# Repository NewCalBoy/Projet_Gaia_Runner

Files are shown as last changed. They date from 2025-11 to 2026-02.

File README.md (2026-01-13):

# Projet Gaïa Runner
Projet de 2ème année 2025 by SERAPHIN Bradley et DAVERAT Arthur

## Description du projet
Le projet consiste a créer un petit robot de type rover avec un bras articulé. La particularité du projet est qu'il est à architecture déporté, c'est-à-dire que le contrôle des roues est gérée par un microcontrôleur, autre que le microcontrôleur principal.

Voici ci-joint un exemple de rover avec un bras articulé.
ExempleGR

Dans un premier temps nous réaliserons d'abord le châssis, puis nous réaliserons dans un second temps la pince.

## Différentes parties
### Partie 1 : Rover
### Partie 2 : Bras robotisé
### Partie 3 : Pilotage
## Présentation
Lien de la présentation : https://www.canva.com/design/DAG3vKNjyPE/KJl2cilKYN6kFEWi7G_Mkw/edit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

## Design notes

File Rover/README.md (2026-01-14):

# Partie 1 : Rover
La partie mobile, dite le Rover, se décompose en 2 partie, les PCBs Esclave c'est-à-dire ceux des roues et le PCB Maître c'est à dire celui qui gère la partie Rover et le bras robotisé.

## Architecture déportée (Avantages et Inconvénients)
L'avantage d'une architecture déportée comme celle choisit pour le Rover est que c'est modulable. En effet chaque PCB Esclave contrôle un moteur et est en liasion I2C avec le PCB Maître, ce qui permet de __passer d'une structure à 4 roues motrices à 6 ou bien 2 roues motrices__.

L'incovénient est que plusieurs PCBs impliquent potentiellement __plus de PCB en panne__.

Voici ci-dessous un schéma du Rover



_Figure 1 : Schéma du Rover_

## Détaille du châssis
Les différentes solutions techniques retenues sont :

<details>
  <summary><strong>Les moteurs DC FIT0186 de chez DFROBOT (JGB37-3530B)</strong></summary>  

Comme le projet consiste à commander le robot le choix d'un moteur DC est pertinent, de plus le modèle choisit présente un encodeur ce qui permet un asservissement en vitesse si nécessaire. Plus de détail dans [Moteur DC](https://github.com/FumesecALPHA/Projet_Gaia_Runner/blob/main/Rover/Moteur_DC).
  
</details>
<details>
  <summary><strong>Les roues omnidirectionnelles</strong></summary>  

Le choix des roues omnidirectionnelles vient du faites qu'il s'agit du moyen le plus adapté pour déplacer notre robot avec une architecture à 4 roues motrices. Plus de détail dans [Roues omnidirectionnelles](https://github.com/FumesecALPHA/Projet_Gaia_Runner/blob/main/Rover/Roues_omnidirectionnelles).
  
</details>
<details>
  <summary><strong>Les PCBs Esclave</strong></summary>  

Le but de ces PCBs est de séparer le contrôle des moteurs DC du PCB Maître, cela permet de s'adapter à un châssis avec 4, 6 ou encore 2 roues motrices. Plus de détail dans [PCB Esclave](https://github.com/FumesecALPHA/Projet_Gaia_Runner/tree/blob/main/Rover/PCB_Slave).
  
</details>

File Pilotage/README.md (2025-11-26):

# Partie 3 : Pilotage
## Description
Cette sous partie concerne la commande du Gaïa Runner, c'est-à-dire l'usage du module Bluetooth pour controler le robot à distance.

## Solution technique
Pour le pilotage du robot, la solution choisit est d'utiliser un module Bluetooth HC05. Il sera connecté sur le PCB principal.

Module Bluetooth HC05

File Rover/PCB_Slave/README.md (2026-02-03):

# PCB Esclave

## Description
Voici le PCB Esclave qui a pour but de gérer la commande des moteurs DC.
<p align="center">
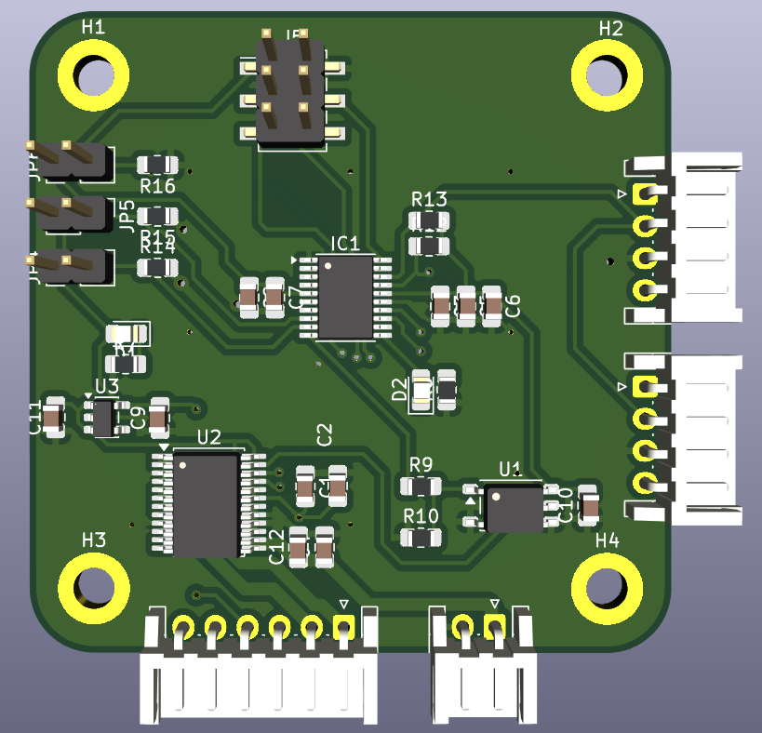
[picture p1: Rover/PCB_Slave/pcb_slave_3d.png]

</p>

Il y a 4 composants principaux : le microcontrolleur, le pont H, le LDO et l'optocoupleur.
Nous avons également 4 connecteurs JST : deux JST pour  l'I2C, un jst pour l'alimentation et un pour le moteur.

## Fonctionnement
### Etape 1
Le PCB Maître communique un octet avec le PCB Esclave via I2C. 
En fonction de la combinaisons des jumpers, l'adresse I2C du PCB Esclave est différente plus de détails dans la section [Adressage I2C]().
### Etape 2
En fonction de l'octet reçu, le PCB Esclave sait s'il doit avancer ou reculer et la vitesse attendue.

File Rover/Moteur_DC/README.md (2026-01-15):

# Moteur DC

Les moteurs choisient sont des moteurs 12V 251 tr/min 18 kg/cm de chez DFROBOT ([Roboshop](https://eu.robotshop.com/fr/products/moteur-dc-12v-251rpm-encodeur?qd=8a6a3a82e29a9eef824b3c39f723b023) ou [DFROBOT](https://www.dfrobot.com/product-634.html))  

## Pourquoi ce choix ?
<ins> __Modélisation :__ </ins>    
On modélise la situation de la façon suivante :  

<ins> __Bilan des forces :__ </ins>  
  
¤ $\overrightarrow{P}$ : le poids  
¤ $\overrightarrow{C_{m1}}$ : couple __d'un__ moteur
¤ $\overrightarrow{F}$ : force d'adhérence
¤ $\overrightarrow{F_r}$ : réaction du support

<ins> __Calcul :__ </ins>  
  
On sait que $\overrightarrow{C_{m1}}=\frac{\overrightarrow{F_{m1}}}{R}$, donc $\overrightarrow{F_{m1}}=\overrightarrow{C_{m1}}*R$  
  
D'après la 2nd loi de Newton :  
  
$\overrightarrow{F_{m1}}+\overrightarrow{F}+\overrightarrow{P}+\overrightarrow{F_r}=m\overrightarrow{a}$

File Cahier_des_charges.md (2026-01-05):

# Cahier des charges
## Partie 1 : Rover


## Partie 2 : Bras articulé


## Partie 3 : Pilotage


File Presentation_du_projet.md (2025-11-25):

# Projet_Gaia_Runner
Projet de 2ème année 2025 by SERAPHIN Bradley et DAVERAT Arthur

## Description du projet
Le projet consiste a créer un petit robot de type rover avec un bras articulé.

Voici ci-joint un exemple de rover avec un bras articulé.
Exemple de rover avec un bras articulé

Dans un premier temps nous réaliserons d'abord le châssis, puis nous réaliserons dans un second temps la pince.

## Présentation
Lien de la présentation : https://www.canva.com/design/DAG3vKNjyPE/KJl2cilKYN6kFEWi7G_Mkw/edit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

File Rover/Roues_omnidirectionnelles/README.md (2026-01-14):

# Roues omnidirectionnelles
## Description
Les roues omnidirectionnelles, dites roues Mecanum, sont capables de se déplacer dans n'importe quelle direction, c'est-à-dire que la roue ne se contente pas d'avancer et de reculer, elle peut translater à gauche ou à droite.
Chacune des quatre roues comporte une série de rouleaux dotés d'un axe de rotation à 45° par rapport au plan de la roue. Aussi il faut 2 roues gauches et 2 roues droites pour notre Rover.

## Déplacement
Pour notre Rover à 4 roues motrices, les déplacement consiste à contrôler le sens de rotation ainsi que la vitesse de rotation. 
  


## Exemple en vidéo

https://github.com/FumesecALPHA/Projet_Gaia_Runner/blob/main/media/video/mecanum_wheel_exemple.mp4

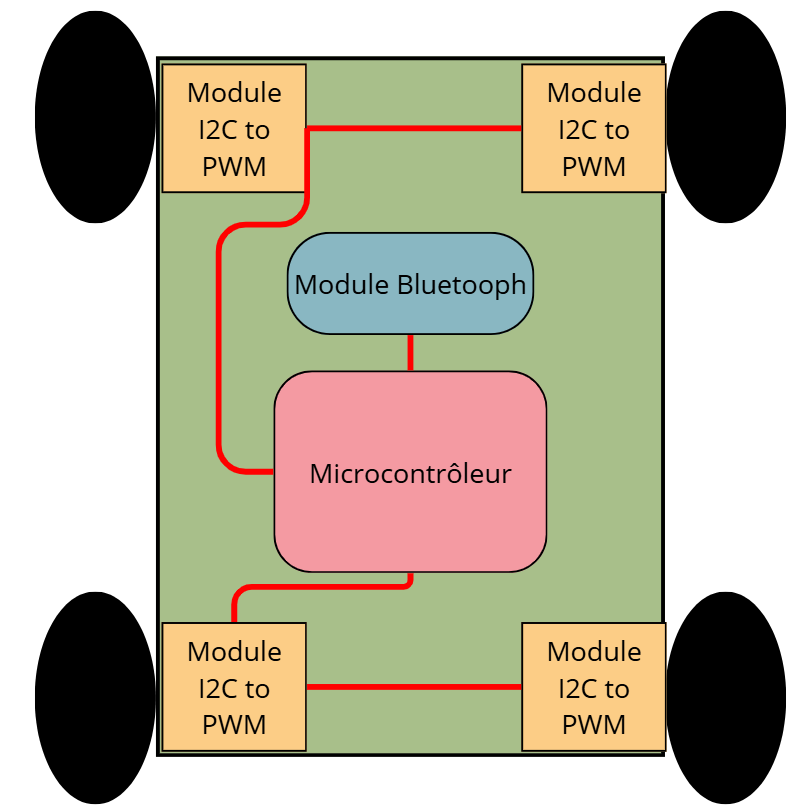
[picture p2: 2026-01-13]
media/picture/Schematic_Rover.png

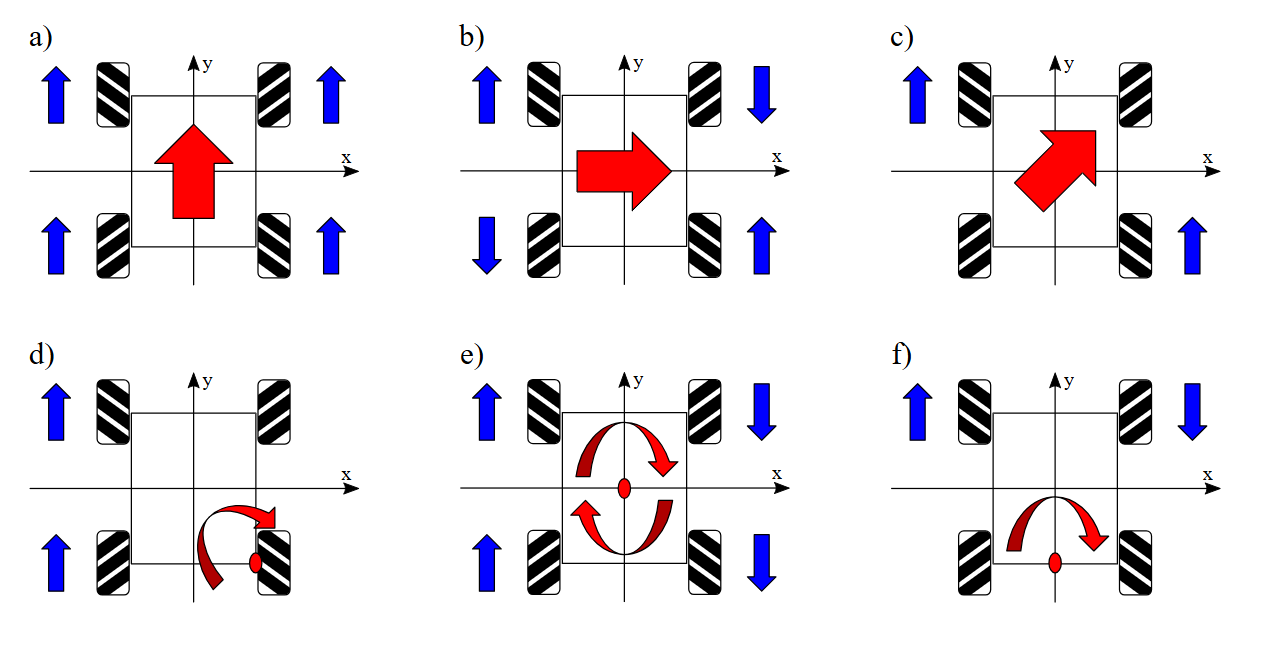
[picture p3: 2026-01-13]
media/picture/Mecanum_schematic.png

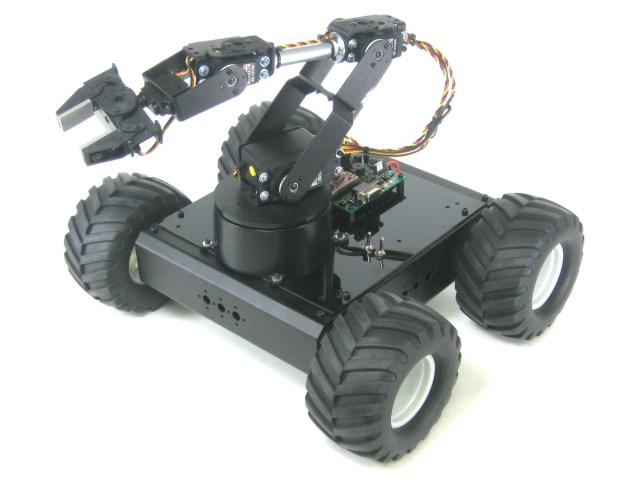
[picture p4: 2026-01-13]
media/picture/Exemple_de_rover_avec_un_bras articule.jpg

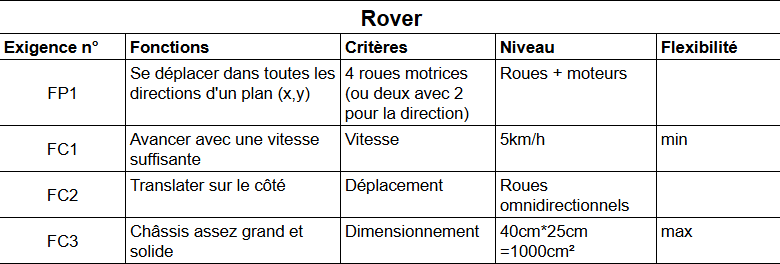
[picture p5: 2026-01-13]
media/picture/CDC_part_Rover.png

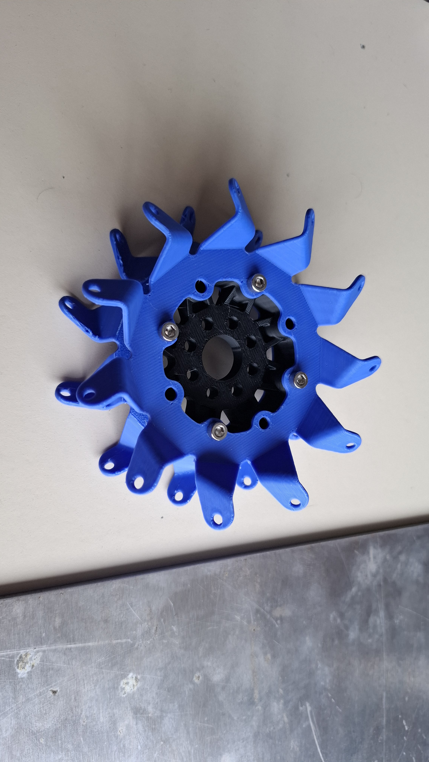
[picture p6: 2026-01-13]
media/picture/picture_made_mecanum.jpg

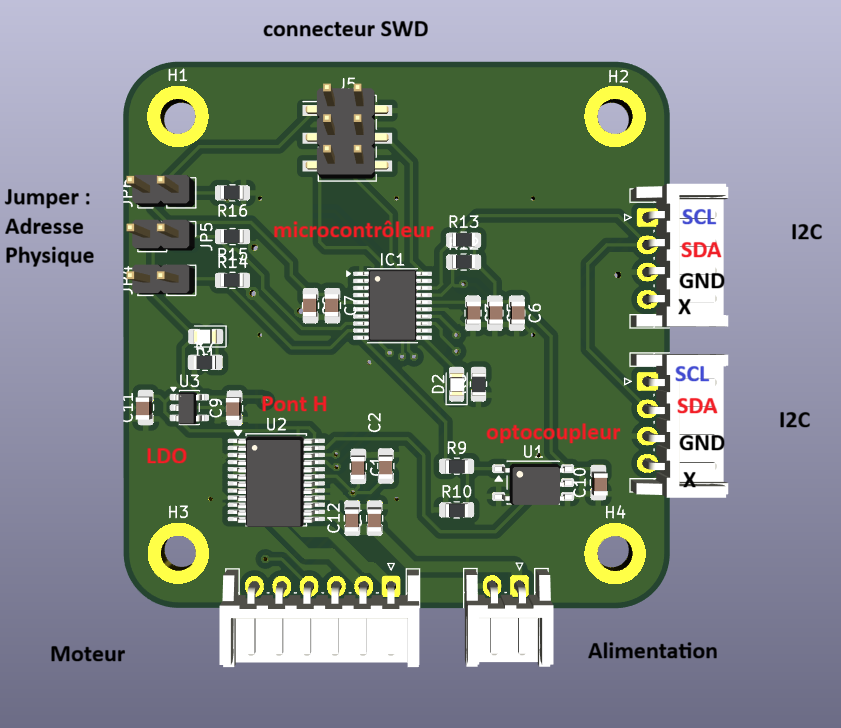
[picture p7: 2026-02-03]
media/picture/PCB_slave.png

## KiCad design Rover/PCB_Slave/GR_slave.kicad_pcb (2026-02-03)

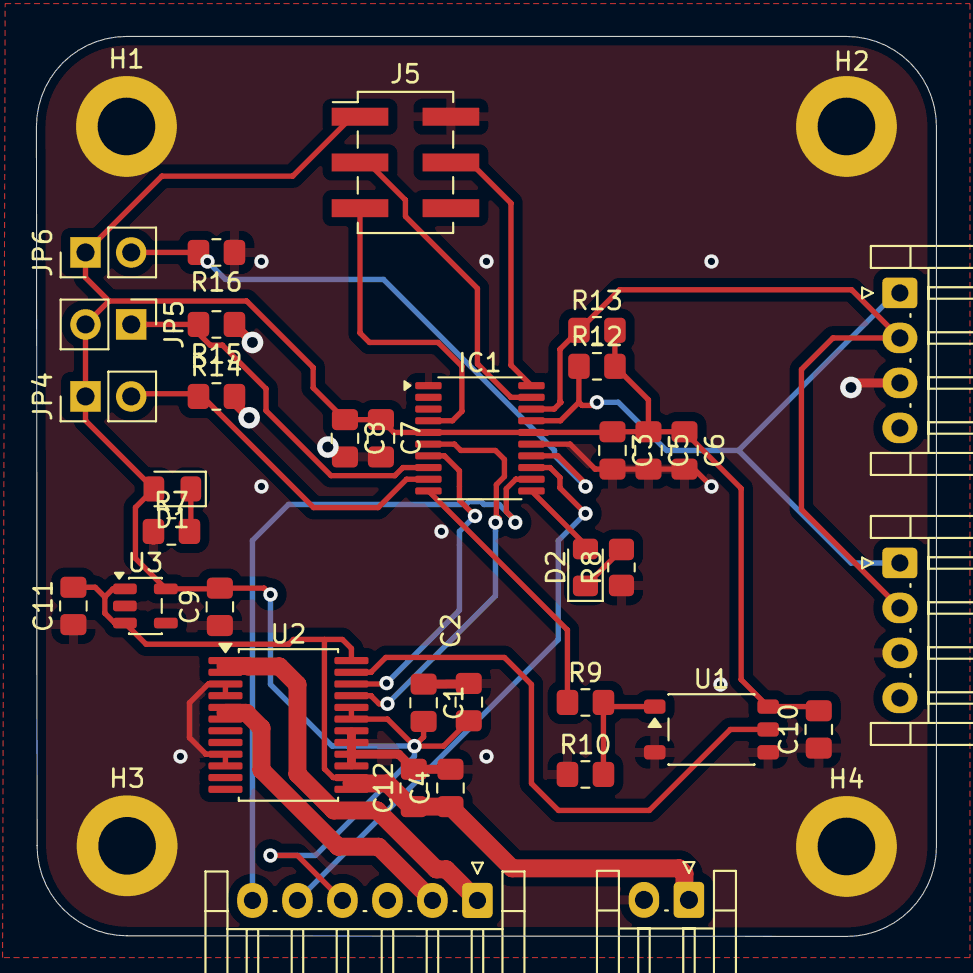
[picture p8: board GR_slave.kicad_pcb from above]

Board: 2 copper layers, 50.0 x 50.0 mm, 39 parts (0 on the bottom side), 23 nets.

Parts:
C1, C12: 0.1u; C_0805_2012Metric_Pad1.18x1.45mm_HandSolder
C2, C4: 10u; C_0805_2012Metric_Pad1.18x1.45mm_HandSolder
C3: 4.7u; C_0805_2012Metric_Pad1.18x1.45mm_HandSolder
C5, C6: 100n; C_0805_2012Metric_Pad1.18x1.45mm_HandSolder
C7: 10n; C_0805_2012Metric_Pad1.18x1.45mm_HandSolder
C8: 1u; C_0805_2012Metric_Pad1.18x1.45mm_HandSolder
C9, C11: 1uF; C_0805_2012Metric_Pad1.18x1.45mm_HandSolder
C10: 0.1uF; C_0805_2012Metric_Pad1.18x1.45mm_HandSolder
D1, D2: LED; LED_0805_2012Metric_Pad1.15x1.40mm_HandSolder
H1, H2, H3, H4: MountingHole_Pad; MountingHole_3.2mm_M3_DIN965_Pad
IC1: STM32F030F4P6; TSSOP-20_4.4x6.5mm_P0.65mm
J2: Conn_01x02; JST_EH_S2B-EH_1x02_P2.50mm_Horizontal
J3, J4: Conn_01x04; JST_EH_S4B-EH_1x04_P2.50mm_Horizontal
J5: T821106A1S100CEU; PinHeader_2x03_P2.54mm_Vertical_SMD
J6: Conn_01x06; JST_EH_S6B-EH_1x06_P2.50mm_Horizontal
JP4, JP5, JP6: Jumper_2_Open; PinHeader_1x02_P2.54mm_Vertical
R7, R8: 270; R_0805_2012Metric_Pad1.20x1.40mm_HandSolder
R9, R10: 210; R_0805_2012Metric_Pad1.20x1.40mm_HandSolder
R12, R13: 4.7k; R_0805_2012Metric_Pad1.20x1.40mm_HandSolder
R14, R15, R16: 10k; R_0805_2012Metric_Pad1.20x1.40mm_HandSolder
U1: TLP2361; SO-5-6_4.55x3.7mm_P1.27mm
U2: TB6612FNG; SSOP-24_5.3x8.2mm_P0.65mm
U3: MIC5219-3.3YM5; SOT-23-5

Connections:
+3.3V: C1.2, C2.1, C3.1, C5.1, C6.1, C7.1, C8.1, C9.2, C10.2, D1.2 (A), IC1.5 (VDDA), IC1.16 (VDD), J5.1, J6.4, JP4.1 (A), JP5.2 (B), JP6.1 (A), R12.2, R13.2, U1.6, U2.19 (STBY), U2.20 (VCC), U3.5 (OUT)
+12V: C4.1, C11.2, C12.1, J2.1, U2.13 (VM2), U2.14 (VM3), U2.24 (VM1), U3.1 (IN), U3.3 (EN)
AIN1: IC1.6 (PA0), U2.21 (AIN1)
AIN2: IC1.7 (PA1), U2.22 (AIN2)
AO1: J6.1, U2.1 (AO1), U2.2 (AO1)
AO2: J6.2, U2.5 (AO2), U2.6 (AO2)
GND: C1.1, C2.2, C3.2, C4.2, C5.2, C6.2, C7.2, C8.2, C9.1, C10.1, C11.1, C12.2, H1.1, H2.1, H3.1, H4.1, IC1.1 (BOOT0), IC1.15 (VSS), J2.2, J3.3, J4.3, J5.2, J6.3, R7.1, R8.1, R10.1, R14.2, R15.1, R16.1, U1.3, U1.4, U2.3 (PGND1), U2.4 (PGND1), U2.9 (PGND2), U2.10 (PGND2), U2.15 (PWMB), U2.16 (BIN2), U2.17 (BIN1), U2.18 (GND), U3.2 (GND)
LED: D2.2 (A), IC1.11 (PA5)
NRST: IC1.4 (NRST), J5.5
unnamed: D1.1 (K), R7.2
unnamed: D2.1 (K), R8.2
unnamed: IC1.8 (PA2), JP5.1 (A), R15.2
unnamed: IC1.9 (PA3), JP4.2 (B), R14.1
unnamed: IC1.14 (PB1), JP6.2 (B), R16.2
unnamed: R9.2, R10.2, U1.1
PWM H-bridge: U1.5, U2.23 (PWMA)
PWM MCU: IC1.10 (PA4), R9.1
SCL: IC1.17 (PA9), J3.1, J4.1, R12.1
SDA: IC1.18 (PA10), J3.2, J4.2, R13.1
SENSOR A ENCODEUR: IC1.13 (PA7), J6.5
SENSOR B ENCODEUR: IC1.12 (PA6), J6.6
SWCLK: IC1.20 (PA14), J5.4
SWDIO: IC1.19 (PA13), J5.3

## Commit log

2026-01-13 Fix link format in README for DC motor section
    Corrected the link format for the DC motor section.
2026-01-13 Fix formatting in README.md for motor details
2026-01-13 Update README with technical solutions and details
    Added details about omnidirectional wheels and slave PCBs.
2026-02-03 Modify image dimensions in README.md
    Updated image size in the PCB Slave README.
2026-02-03 Add image to PCB Slave README
    Added an image to the PCB Slave README for better visualization.
2026-02-03 Enhance PCB Slave README with image and formatting
    Updated the README to include an image and improved formatting.
2026-02-03 Update README with new PCB Slave image
    Added a new image to the README for PCB Slave.
2026-02-03 Fix image source path in PCB Slave README
    Updated image source path in README for PCB Slave.
2026-02-03 Fix image tag in PCB Slave README
2026-02-03 Update README with I2C communication details
    Added a new section about I2C communication and addressing.
2026-02-03 Update README with details on components and connectors
    Added information about main components and connectors.
2026-02-03 Update image path in PCB Slave README
